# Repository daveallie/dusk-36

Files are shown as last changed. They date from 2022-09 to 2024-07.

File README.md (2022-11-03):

<h1 align="center">Dusk 36 Keyboard</h1>
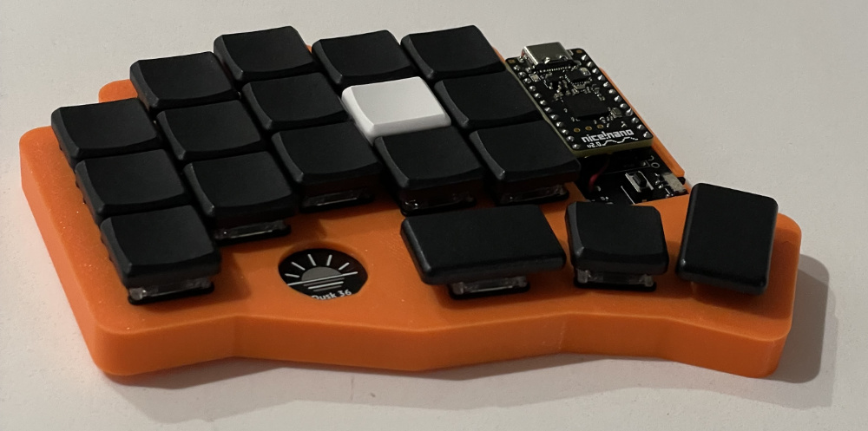
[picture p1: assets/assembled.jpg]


Dusk 36 is a 36-key low-profile split ergo keyboard based off https://github.com/weteor/3W6 and 
https://github.com/davidphilipbarr/Sweep.

The Dusk 36 is designed around the nice!nano v2.0 microcontroller in order to be a true wireless keyboard (no cables
between halves or from the keyboard to the computer). This board's layout was generated with 
[my fork of Ergogen](https://github.com/daveallie/ergogen/tree/daveallie-improvements) (which includes a few small 
changes), and then routed by hand in KiCad.

### PCB Preview

| Left | Right |
|---|---|
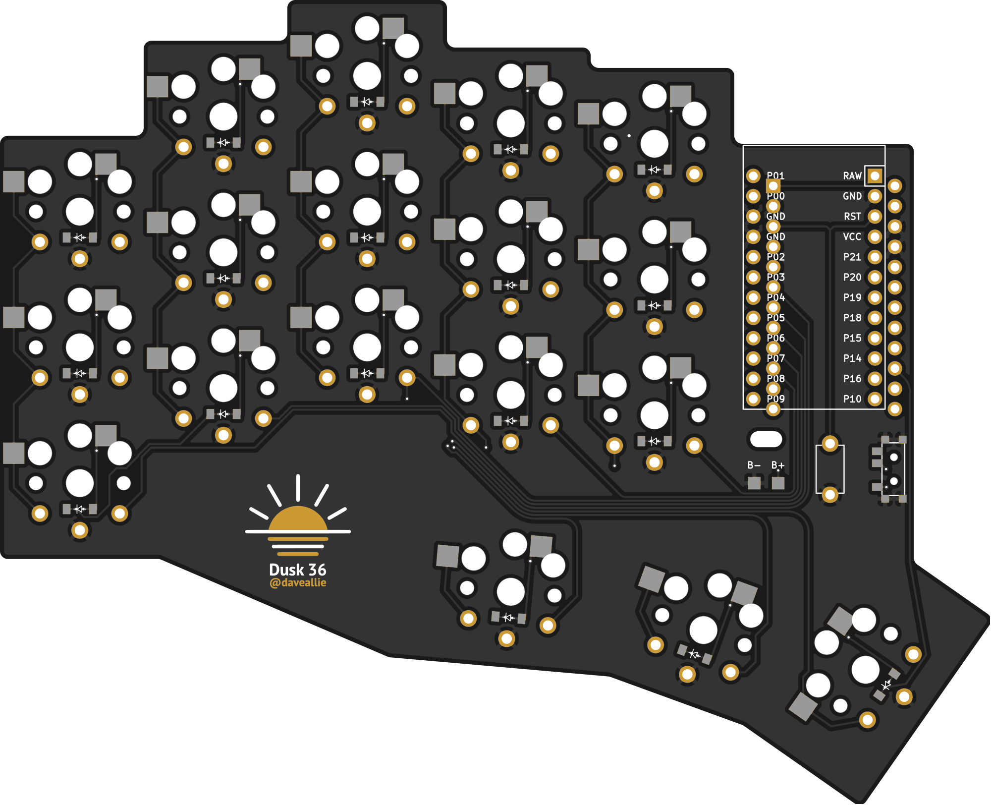
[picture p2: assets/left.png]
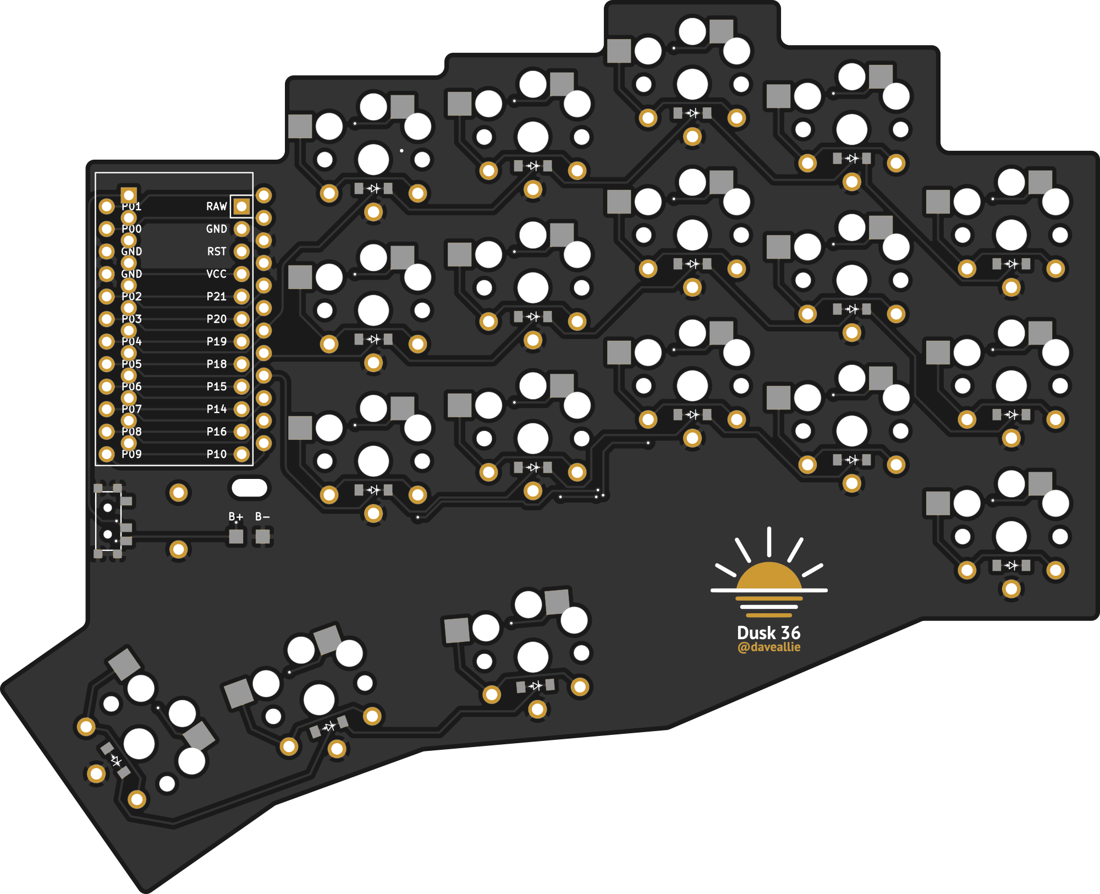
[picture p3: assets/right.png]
|  |  |

### BOM

**Hardware for PCB**
- 2 x [nice!nano v2.0](https://keebd.com/products/nice-nano?variant=41688983240856)
- 1 x [Kailh Low Profile Switches Hot-swappable PCB Socket Sip socket Hot Plug (50 pack)](https://www.aliexpress.com/item/1005003575767699.html)
- 2 x [40 Pin Machined IC Breakable Female Header Strip](https://keebd.com/products/40-pin-machined-ic-breakable-female-header-strip?variant=40383060410520)
- Pins (pick one)
  - 48 x [Single Post Terminal Connector Through Hole Gold 0.020" (0.51mm) Dia](https://www.digikey.com.au/en/products/detail/mill-max-manufacturing-corp/3320-0-00-15-00-00-03-0/4147392)
  - 2 x [Mill-Max Low Profile Controller Pins (Pack of 25)](https://keebd.com/products/mill-max-low-profile-controller-pins-pack-of-25?variant=41055232458904)
- 2 x [EG1215AA Switch](https://www.digikey.com.au/en/products/detail/e-switch/EG1215AA/9559277)
- 2 x [PTS636 SK43 LFS button](https://www.digikey.com.au/en/products/detail/c-k/PTS636-SK43-LFS/10071716)
- 2 x [Polymer Lithium Ion Battery (LiPo) 3.7V 120mAh](https://core-electronics.com.au/lipo-polymer-lithium-ion-battery-120mah.html)
- 36 x SOD-123 diode

**Switches and Keycaps**
- 4 x [Kailh low profile Switch 1350 Chocolate Keyboard Switch RGB SMD kailh Mechanical Keyboard white stem clicky hand feeling (10 pack)](https://www.aliexpress.com/item/32959996455.html)
- 3 x [MBK Low Profile Keycaps - 1u Black (10 pack)](https://keebd.com/products/mbk-low-profile-keycaps?variant=41506944909464)
- 1 x [MBK Low Profile Keycaps - 1u Homing White (2 pack)](https://keebd.com/products/mbk-low-profile-keycaps?variant=41506944811160)
- 1 x [MBK Low Profile Keycaps - 1.5u Black (5 pack)](https://keebd.com/products/mbk-low-profile-keycaps?variant=41506944975000)

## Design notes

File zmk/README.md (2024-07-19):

# Dusk 36 ZMK Shield

## Keymap

Default keymap inspired by Ben Vallack's [Colemak 5x3 Split](https://configure.zsa.io/planck-ez/layouts/4D3ym/jYYjx/0/42/) layout.

## Building

Pushing to GitHub will build the firmware.

### Building Locally

The first time you run this, you'll need to run the setup script:

```shell
docker run --rm -it -v $(pwd):/workspace/zmk-config zmkfirmware/zmk-build-arm:3.5 /workspace/zmk-config/setup.sh
```

To build the images, run:

```shell
docker run --rm -it -v $(pwd):/workspace/zmk-config zmkfirmware/zmk-build-arm:3.5 /workspace/zmk-config/build.sh
```

The built uf2 files will be in the `build/artifacts` directory.

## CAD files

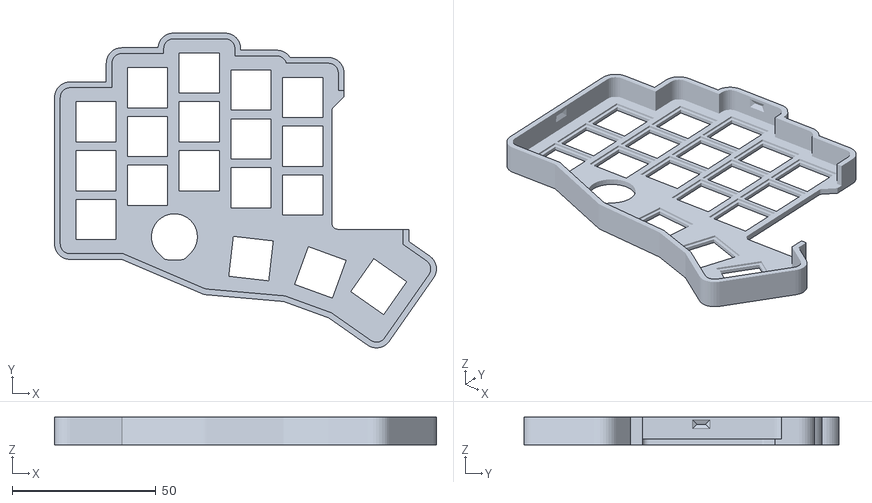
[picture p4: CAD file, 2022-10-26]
case/dusk-36-case-right-top.stl
133.0 x 109.6 x 9.65

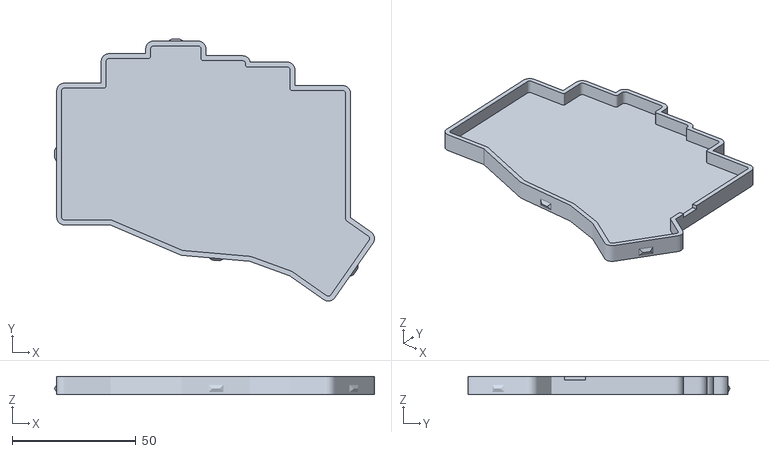
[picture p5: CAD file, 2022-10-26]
case/dusk-36-case-left-bottom.stl
129.4 x 106.1 x 7.45

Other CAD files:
case/dusk-36-case-left-top.stl
case/dusk-36-case-right-bottom.stl
case/case.f3d

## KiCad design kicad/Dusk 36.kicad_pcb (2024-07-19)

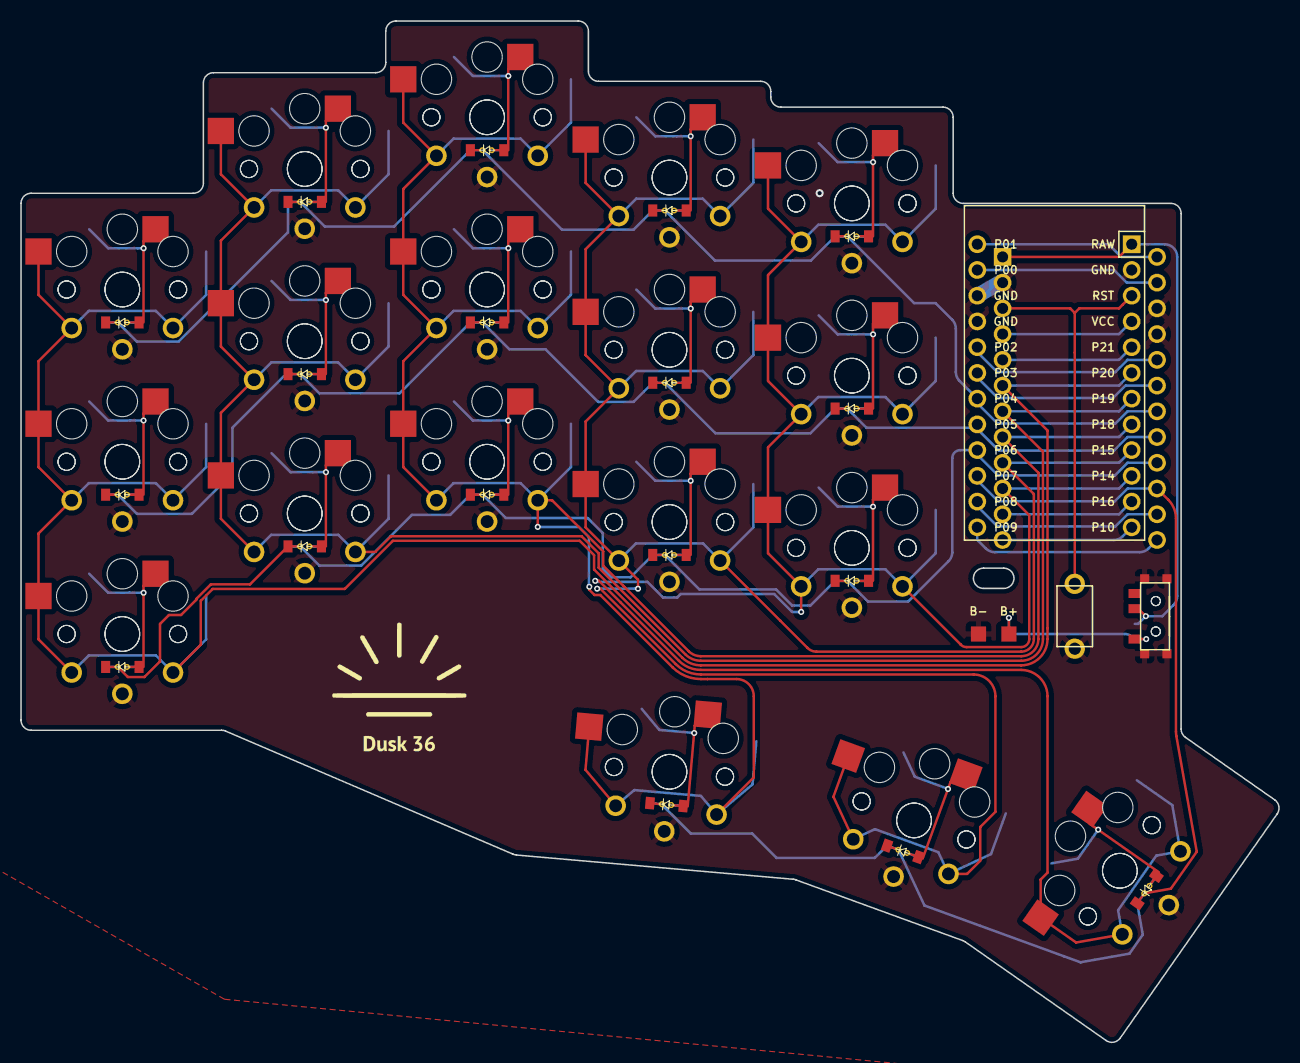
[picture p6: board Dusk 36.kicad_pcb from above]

Board: 2 copper layers, 124.2 x 100.8 mm, 61 parts (1 on the bottom side), 41 nets.

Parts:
B1: SW_TACT_PTS636_SK43_LFS
D1, D2, D3, D4, D5, D6, D7, D8, D9, D10, D11, D12, D13, D14, D15, D16, D17, D18: ComboDiode
MCU1, MCU2: ProMicro
PAD1, PAD2: SMDPad
S1, S2, S3, S4, S5, S6, S7, S8, S9, S10, S11, S12, S13, S14, S15, S16, S17, S18, S19, S20, S21, S22, S23, S24, S25, S26, S27, S28, S29, S30, S31, S32, S33, S34, S35, S36: PG1350
T1, T2: SPDT_C128955

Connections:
BPos: PAD1.1, T1.1, T2.3
GND: B1.1, MCU1.2, MCU1.15, MCU1.16, MCU2.2, MCU2.15, MCU2.16, PAD2.1, S2.2, S4.2, S6.2, S8.2, S10.2, S12.2, S14.2, S16.2, S18.2, S20.2, S22.2, S24.2, S26.2, S28.2, S30.2, S32.2, S34.2, S36.2
P0: MCU1.14, MCU2.14
P1: MCU1.13, MCU2.13
P2: MCU1.17, MCU2.17
P3: MCU1.18, MCU2.18
P4: D3.1, D6.1, D9.1, D12.1, D15.1, MCU1.19, MCU2.19
P5: D2.1, D5.1, D8.1, D11.1, D14.1, MCU1.20, MCU2.20
P6: D1.1, D4.1, D7.1, D10.1, D13.1, MCU1.21, MCU2.21
P7: D16.1, D17.1, D18.1, MCU1.22, MCU2.22
P8: MCU1.23, MCU2.23
P9: MCU1.24, MCU2.24
P10: MCU1.12, MCU2.12
P14: MCU1.10, MCU2.10, S25.2, S26.1, S27.2, S28.1, S29.2, S30.1, S35.2, S36.1
P15: MCU1.9, MCU2.9, S19.2, S20.1, S21.2, S22.1, S23.2, S24.1, S33.2, S34.1
P16: MCU1.11, MCU2.11
P18: MCU1.8, MCU2.8, S13.2, S14.1, S15.2, S16.1, S17.2, S18.1, S31.2, S32.1
P19: MCU1.7, MCU2.7, S7.2, S8.1, S9.2, S10.1, S11.2, S12.1
P20: MCU1.6, MCU2.6, S1.2, S2.1, S3.2, S4.1, S5.2, S6.1
P21: MCU1.5, MCU2.5
RAW: MCU1.1, MCU2.1, T1.2, T2.2
RST: B1.2, MCU1.3, MCU2.3
VCC: MCU1.4, MCU2.4
far_thumb: D18.2, S35.1
home_thumb: D17.2, S33.1
index_bottom: D10.2, S19.1
index_home: D11.2, S21.1
index_top: D12.2, S23.1
inner_bottom: D13.2, S25.1
inner_home: D14.2, S27.1
inner_top: D15.2, S29.1
middle_bottom: D7.2, S13.1
middle_home: D8.2, S15.1
middle_top: D9.2, S17.1
near_thumb: D16.2, S31.1
pinky_bottom: D1.2, S1.1
pinky_home: D2.2, S3.1
pinky_top: D3.2, S5.1
ring_bottom: D4.2, S7.1
ring_home: D5.2, S9.1
ring_top: D6.2, S11.1

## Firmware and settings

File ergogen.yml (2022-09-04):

units:
  kx: cx
  ky: cy
  px: 2
  py: 2
points:
  key:
    footprints:
      choc_hotswap:
        type: choc
        params:
          hotswap: true
          reverse: true
          keycaps: true
        nets:
          from: =colrow
          to: =column_net
      choc:
        type: choc
        anchor:
          rotate: 180
        nets:
          from: =column_net
          to: GND
        params:
          keycaps: true
          reverse: true
      diode:
        type: diode
        nets:
          from: =colrow
          to: =row_net
        params:
          tht: false
          internalVia: true
        anchor:
          shift: [0, -3.25]
  zones:
    matrix:
      key:
        padding: ky
        tags:
          1u: true
      columns:
        pinky:
          spread: kx
          key:
            column_net: P20
        ring:
          spread: kx
          stagger: 0.7 ky
          key:
            column_net: P19
        middle:
          spread: kx
          stagger: 0.3 ky
          key:
            column_net: P18
        index:
          spread: kx
          stagger: -0.35 ky
          key:
            column_net: P15
        inner:
          spread: kx
          stagger: -0.15 ky
          key:
            column_net: P14
      rows:
        bottom:
          row_net: P6
        home:
          row_net: P5
        top:
          row_net: P4
    thumbfan:
      anchor:
        ref: matrix_inner_bottom
        shift: [-1 kx, -1.3 ky]
      columns:
        near:
          rotate: -5
          key:
            column_net: P18
            tags:
              15u: true
        home:
          spread: 1.13 kx
          rotate: -15
          origin: [-0.45 kx, -ky]
          key:
            column_net: P15
            tags:
              1u: true
        far:
          spread: 1.01kx
          rotate: 75
          origin: [-0.01 kx, 0.167ky]
          key:
            column_net: P14
            tags:
              15u: true
      rows:
        thumb:
          row_net: P7
outlines:
  exports:
    raw:
      1u:
        type: keys
        side: left
        size: [kx + px, ky + py]
        tags: [1u]
      15u:
        type: keys
        side: left
        size: [1.5 kx + px, ky + py]
        tags: [15u]
    thumbfan_glue:
      - type: polygon
        points:
          - ref: matrix_inner_bottom
            shift: [0.5 kx + 0.5px, 0.5 ky + 0.5 py]
          - ref: thumbfan_far_thumb
            shift: [0.75 kx + 0.5px, 0.5 ky + 0.5 py]
          - ref: thumbfan_far_thumb
            shift: [-0.75 kx - 0.5px, 0.5 ky + 0.5 py]
          - ref: thumbfan_near_thumb
            shift: [0.75 kx + 0.5 px, -0.5 ky - 0.5 py]
          - ref: thumbfan_near_thumb
            shift: [-0.75 kx - 0.5 px, -0.5 ky - 0.5 py]
          - ref: matrix_pinky_bottom
            shift: [0.5 kx + 0.5 py, -0.5 ky - 0.5 py]
          - ref: matrix_pinky_home
    controller_area:
      - type: rectangle
        anchor:
          ref:
            - matrix_inner_top
          shift: [0, 0]
          rotate: 270
        size: [60, 32.5]
    keycaps:
      1u:
        type: keys
        side: left
        size: [1kx - 0.5, 1ky - 0.5]
        bound: false
        corner: 1
        tags: [1u]
      15u:
        type: keys
        side: left
        size: [1.5kx - 0.5, 1ky - 0.5]
        bound: false
        corner: 1
        tags: [15u]
    keywell:
      - type: outline
        name: raw
      - type: outline
        name: thumbfan_glue
        operation: add
    base_outline:
      - type: outline
        name: keywell
      - type: outline
        name: controller_area
        operation: add
    battery_wire_hole:
      - type: rectangle
        anchor:
          ref:
            - matrix_inner_bottom
          shift: [12, -4]
        size: [4, 2]
        corner: 1
    pcb:
      - type: outline
        name: base_outline
        fillet: 0.5px
      - type: outline
        name: battery_wire_hole
        operation: subtract
pcbs:
  "Dusk 36":
    outlines:
      edge:
        outline: pcb
        layer: Edge.Cuts
      keycaps:
        outline: keycaps
        layer: Eco1.User
    footprints:
      mcu_front:
        type: promicro
        params:
          orientation: up
          side: F
          batteryPins: true
        anchor:
          ref:
            - matrix_inner_top
          shift: [20, -18]
          rotate: 270
      mcu_back:
        type: promicro
        params:
          orientation: up
          side: B
          batteryPins: true
        anchor:
          ref:
            - matrix_inner_top
          shift: [22.5, -19.25]
          rotate: 270
      pad_plus:
        type: pad
        anchor:
          ref:
            - matrix_inner_bottom
          shift: [15.5, -8.5]
        params:
          front: true
          back: true
          width: 1.5
          height: 1.5
          align: down
          text: "B+"
        nets:
          net: BPos
      pad_minus:
        type: pad
        anchor:
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

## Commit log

2022-08-23 Fix up PCB outline
    [ergogen.yml]
2022-08-28 Update ergogen file and route board
    [dalliekeeb.kicad_pcb]
2022-08-31 Cleanup traces and make ✨curvy✨
    [dalliekeeb.kicad_pcb]
2022-09-04 Add pcb art
    [dalliekeeb.kicad_pcb]
2022-09-04 Rename board to Dusk 36
    [Dusk 36.kicad_pcb]
2022-09-04 Add gerber files
    [Dusk 36-B_Cu.gbr, Dusk 36-B_Mask.gbr, Dusk 36-B_Paste.gbr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]
2022-10-12 Update pins option in README BOM
2022-10-26 Add case f3d and stl files
    [case.f3d, dusk-36-case-left-bottom.stl, dusk-36-case-left-top.stl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]
2022-11-03 Add assembled photo
2024-07-19 Update kicad files to latest version
    [Dusk 36.kicad_pcb]
